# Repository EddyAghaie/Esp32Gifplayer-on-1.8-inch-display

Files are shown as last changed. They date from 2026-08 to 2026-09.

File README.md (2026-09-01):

# Esp32Gifplayer-on-1.8-inch-display

⚠️ **Please read the README before using this project.**

A high-speed ESP32 GIF player with Wi-Fi upload, optimized playback, 1.8" ST7735 TFT support, and LittleFS storage.

# ESP32 High-Speed GIF Player

This project is designed as one of the **fastest and simplest ways to play GIF animations on a standard ESP32 over Wi-Fi**, without requiring an SD card or an internet connection.

GIFs are uploaded from a smartphone over Wi-Fi, processed directly in the browser, converted into an optimized custom binary format, and stored in **LittleFS**. The ESP32 then reads the optimized frames directly from flash memory and plays them continuously on the TFT display.

The hardware is designed around a **Wemos D1 Mini ESP32**, a **1.8-inch ST7735 TFT display**, and a compact **650mAh 3.7V Li-ion battery** with a **TP4056 charging module**.

---

# Features

* ⚡ High-speed GIF playback
* 📺 1.8-inch ST7735 TFT display
* 🖥️ 160×128 landscape resolution
* 📡 Built-in ESP32 Wi-Fi Access Point
* 📱 Upload GIFs directly from a smartphone
* 💾 Store animations in LittleFS
* 🚫 No SD card required
* 🌐 No internet connection required
* 🚀 Optimized SPI display communication
* 🧩 Custom lightweight `GFA1` animation format
* 🔄 Continuous GIF playback
* 📷 Automatic QR code generation
* 📱 Mobile-friendly upload interface
* 📲 PWA support / Add to Home Screen
* 🔄 Factory reset using 5 power cycles
* 💻 GIF decoding is performed in the browser using pure JavaScript
* 📦 Maximum 30 output frames per GIF
* 🔋 650mAh 3.7V Li-ion battery
* 🔌 TP4056 Li-ion battery charging
* ⏻ ON/OFF power switch
* 🧳 Portable battery-powered design

---

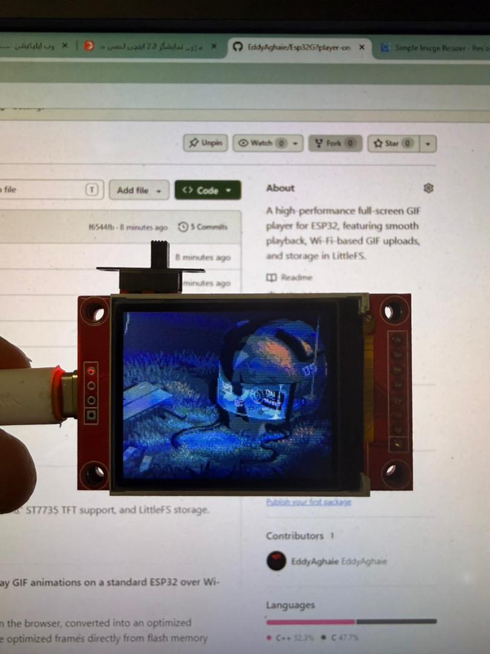
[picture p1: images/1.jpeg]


---

# Hardware

## Required Hardware

* **Wemos D1 Mini ESP32**
* 1.8-inch ST7735 SPI TFT display, 160×128
* **650mAh 3.7V Li-ion battery**
* **TP4056 Li-ion charging module with USB input**
* ON/OFF slide switch
* 5V USB power source for charging
* Jumper wires
* Appropriate regulated power circuit for the ESP32

The project uses a **Wemos D1 Mini ESP32** as the main controller.

The device does not require:

* ESP32-S3
* ESP32-C3
* SD card
* Internet connection
* Cloud service

---

# Power & Charging

The project uses a **650mAh 3.7V Li-ion battery** as the portable power source.

The TP4056 module is used for **charging the Li-ion battery**.

## Battery Connection

Connect the battery to the battery terminals of the TP4056:

```text
650mAh Li-ion Battery
       │
       ├── Battery + ───────> TP4056 BAT+
       │
       └── Battery − ───────> TP4056 BAT−
```

## USB Charging

The TP4056 module is charged through its **USB input**.

Simply connect a standard **5V USB power source** to the USB port on the TP4056:

```text
5V USB Charger
      │
      ▼
TP4056 USB Port
      │
      ▼
650mAh Li-ion Battery
```

No separate wiring to `IN+` or `IN−` is required when using the USB connector on the TP4056 module.

> **Important:** Use a suitable 5V USB power source for charging. Do not connect the battery to the USB input.

---

# Power Switch

The ON/OFF switch is placed in the positive power path between the battery power output and the ESP32 power circuit.

Recommended power flow:

```text
650mAh 3.7V Li-ion Battery
          │
          ▼
     ON/OFF Switch
          │
          ▼
 Proper Voltage Regulation
          │
          ▼
 Wemos D1 Mini ESP32
```

The TP4056 remains responsible for charging the battery through its USB connector.

> **Important:** The TP4056 is a battery charger, not a 3.3V regulator. Do not connect a raw 3.7–4.2V Li-ion battery directly to the ESP32 `3V3` pin. Use the appropriate regulated power circuit for the Wemos D1 Mini ESP32.

---

# Complete Power Flow

```text
                USB 5V
                  │
                  ▼
           ┌─────────────┐
           │   TP4056    │
           │ USB Charger │
           └──────┬──────┘
                  │
                  ▼
        650mAh 3.7V Li-ion
                  │
                  ▼
            ON/OFF Switch
                  │
                  ▼
        Proper Voltage Regulator
                  │
                  ▼
        Wemos D1 Mini ESP32
                  │
                  ▼
             ST7735 TFT
```

---

# TFT Pinout

The following pin configuration is used by the firmware:

| ST7735 Pin | ESP32 GPIO | Function |
| --- | ---: | --- |
| VCC | 3.3V | Power |
| GND | GND | Ground |
| SCK / SCL  | GPIO 18 | SPI Clock |
| SDA / MOSI | GPIO 23 | SPI MOSI |
| CS | GPIO 5 | Chip Select |
| DC / A0 | GPIO 21 | Data / Command |
| RST / RES  | GPIO 2 | Display Reset  |
| LED / BL | GPIO 4 | Backlight |

### Wiring
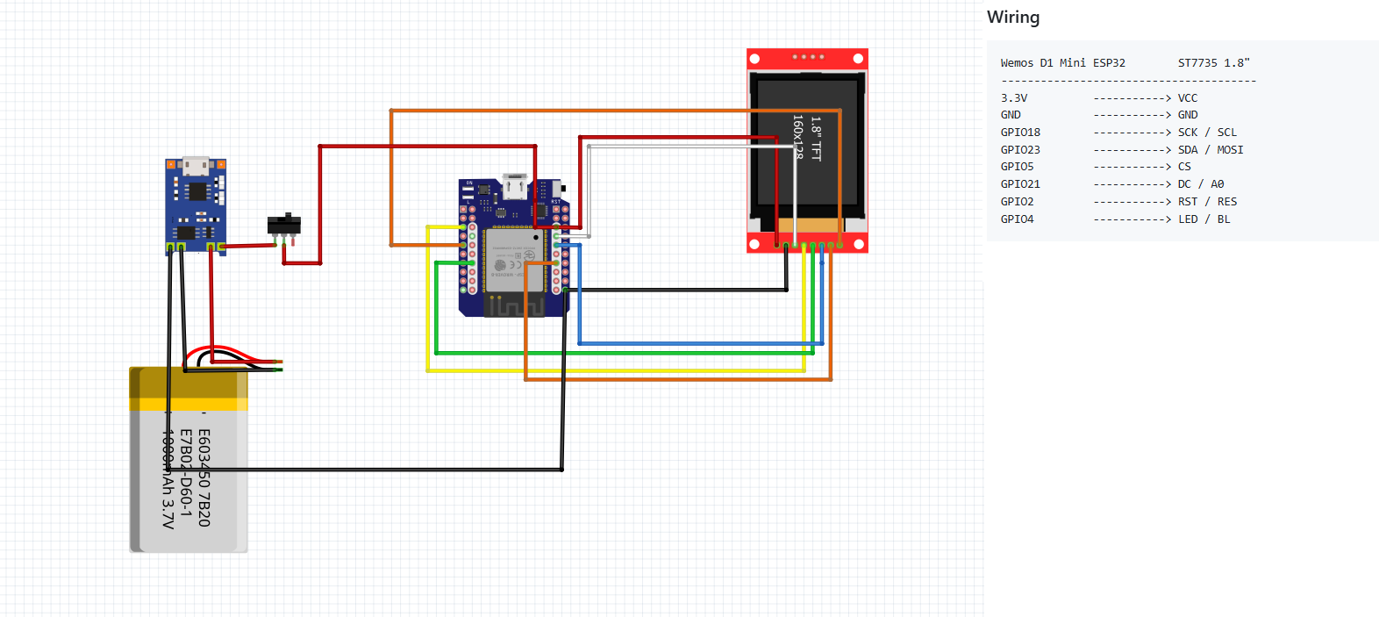
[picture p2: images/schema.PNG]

```text
Wemos D1 Mini ESP32        ST7735 1.8"
---------------------------------------
3.3V          -----------> VCC
GND           -----------> GND
GPIO18        -----------> SCK / SCL
GPIO23        -----------> SDA / MOSI
GPIO5         -----------> CS
GPIO21        -----------> DC / A0
GPIO2         -----------> RST / RES
GPIO4         -----------> LED / BL
```

> **Important:** The display logic is configured for 3.3V. Do not apply 5V directly to 3.3V-only display pins.

---

# ESP32 GPIO Summary

```text
ST7735 SCK  → GPIO18
ST7735 MOSI → GPIO23
ST7735 CS   → GPIO5
ST7735 DC   → GPIO21
ST7735 RST  → GPIO2
ST7735 LED  → GPIO4
```

---

# Display Configuration

The firmware is configured for:

```text
Display:     ST7735
Resolution:  160 × 128
Orientation: Landscape
```

The default rotation is:

```cpp
tft.setRotation(1);
```

If the image is upside down, try:

```cpp
tft.setRotation(3);
```

---

# SPI Configuration

The default ESP32 SPI pins used by the project are:

```text
MOSI = GPIO23
SCK  = GPIO18
```

Display control:

```text
CS  = GPIO5
DC  = GPIO21
RST = GPIO2
BL  = GPIO4
```

---

# Arduino IDE Configuration

Before uploading the firmware, configure Arduino IDE correctly.

## Board

Select:

```text
Tools
→ Board
→ ESP32 Arduino
→ ESP32 Dev Module
```

The firmware uses the standard ESP32 Arduino configuration and is designed to run on the **Wemos D1 Mini ESP32**.

## Recommended Settings

```text
Board:             ESP32 Dev Module
CPU Frequency:     240MHz (WiFi/BT)
Flash Frequency:   80MHz
Flash Mode:        QIO
Upload Speed:      921600
Partition Scheme:  2MB APP / 2MB Filesystem
```

> The exact names of some options may differ depending on your ESP32 Arduino Core version.

---

# Partition Scheme

The recommended partition layout is:

```text
+-----------------------------+
|       APP / Firmware        |
|           2 MB              |
+-----------------------------+
|     LittleFS / Filesystem   |
|           2 MB              |
+-----------------------------+
```

Select a partition scheme that provides approximately:

```text
2 MB APP
2 MB Filesystem
```

Depending on the ESP32 Arduino Core version, the filesystem may be displayed as:

```text
SPIFFS
```

or:

```text
Filesystem
```

Even if the menu says **SPIFFS**, this project uses the **LittleFS API** in the firmware.

The filesystem partition is used to store:

```text
/current.anim
```

and optionally:

```text
/icon.png
```

---

# Required Libraries

Install the following libraries before compiling.

## Adafruit

```text
Adafruit GFX Library
Adafruit ST7735 and ST7789 Library
Adafruit BusIO
```

## ESPAsyncWebServer

Install:

```text
ESPAsyncWebServer
AsyncTCP
```

Use the **ESP32Async** versions compatible with the ESP32 Arduino Core.

## Included with ESP32 Core

These are normally already included:

```text
SPI
WiFi
FS
LittleFS
Preferences
```

## QR Code

The project requires:

```text
QRCodeGen.h
QRCodeGen.c
```

Place both files next to the `.ino` file.

The QR implementation is based on the `ricmoo/QRCode` project with modifications required by this project.

---

# Project Structure

Your project folder should look like:

```text
Esp32Gifplayer-on-1.8-inch-display/
│
├── GifFrame/
│   ├── GifFrame.ino
│   ├── QRCodeGen.h
│   └── QRCodeGen.c
│
├── images/
│   ├── 1.jpeg
│   ├── 2.jpg
│   └── ...
│
└── README.md
```

---

# How the Project Works

The complete process is:

```text
ESP32
  │
  ├── Creates Wi-Fi Access Point
  │
  ▼
QR Code 1
  │
  ▼
Phone connects to ESP32 Wi-Fi
  │
  ▼
QR Code 2
  │
  ▼
http://192.168.4.1/
  │
  ▼
Upload GIF / Image
  │
  ▼
Browser processes the file
  │
  ├── Decode GIF
  ├── Resize
  ├── Crop / Cover
  ├── Convert RGB888 → RGB565
  └── Build GFA1
  │
  ▼
Upload GFA1 to ESP32
  │
  ▼
LittleFS
  │
  ▼
/current.anim
  │
  ▼
ESP32 reads frames
  │
  ▼
ST7735
  │
  ▼
Continuous playback
```

---

# First Boot

When the ESP32 does not have an animation stored in LittleFS, it starts an open Wi-Fi Access Point.

The SSID is automatically generated from the ESP32 MAC address.

Example:

```text
TABLOA1B2
```

The display shows a QR code containing the Wi-Fi configuration.

Scan this QR code with your smartphone to connect to the ESP32.

The Wi-Fi network is open and does not require a password.

---

# Opening the Upload Page

After a smartphone connects to the ESP32 Access Point, the display automatically changes to a second QR code.

This QR code contains:

```text
http://192.168.4.1/
```

Scan it to open the upload page.

You can also manually enter:

```text
http://192.168.4.1
```

into the browser.

No internet connection is required.

---

# Uploading GIFs

The web interface allows you to select an image or GIF from your phone.

Supported image types depend on the browser, including common formats such as:

```text
JPG
PNG
WEBP
BMP
GIF
```

The original GIF is **not** stored on the ESP32.

Instead, the browser processes the GIF before uploading it.

---

# Browser-Side GIF Processing

The ESP32 does not need the `AnimatedGIF` library.

GIF decoding is performed using pure JavaScript running inside the smartphone browser.

The browser performs:

```text
GIF decoding
     ↓
Frame extraction
     ↓
Frame composition
     ↓
Resize / Cover
     ↓
160×128 output
     ↓
RGB888 → RGB565
     ↓
GFA1 generation
     ↓
Wi-Fi upload
```

This significantly reduces the processing required by the ESP32 during playback.

---

# Image Resolution

The target resolution is:

```text
160 × 128
```

Images are automatically resized using a cover-style algorithm.

The goal is to fill the display while avoiding unwanted empty areas.

For animated GIFs, the browser limits the output to:

```text
MAX_FRAMES = 30
```

If the original GIF contains more than 30 frames, frames are sampled to reduce the final file size.

---

# LittleFS Storage

The processed animation is stored as:

```text
/current.anim
```

The ESP32 reads the animation directly from LittleFS.

The animation remains stored after power is removed.

When the ESP32 boots again, it automatically detects:

```text
/current.anim
```

and starts playing it.

---

# GFA1 Format

The project uses a custom binary format called:

```text
GFA1
```

Instead of decoding GIF files on the ESP32, the GIF is converted into raw RGB565 frames.

## File Header

```text
Byte 0-3    : "GFA1"
Byte 4-5    : Width
Byte 6-7    : Height
Byte 8-9    : Frame Count
```

Each frame contains:

```text
2 bytes              Frame delay
width × height × 2   RGB565 pixel data
```

All header integers use little-endian format.

Pixel data is stored in the byte order required by the ST7735 transfer.

---

# Frame Size

Each 160×128 RGB565 frame requires:

```text
160 × 128 × 2
```

which equals:

```text
40,960 bytes
```

approximately:

```text
40 KB per frame
```

Therefore, a 30-frame animation can require roughly:

```text
1.2 MB
```

plus headers and frame delays.

This is why the recommended filesystem partition is:

```text
2 MB
```

---

# Playback

After a successful upload, the ESP32 opens:

```text
/current.anim
```

and starts playing it.

The animation loops continuously:

```text
Frame 1
   ↓
Frame 2
   ↓
Frame 3
   ↓
...
   ↓
Last Frame
   ↓
Frame 1
   ↓
Repeat
```

The display is updated using SPI and the frames are read directly from LittleFS.

---

# Factory Reset

A factory reset is available without a physical reset button.

Power-cycle the ESP32:

```text
ON → OFF
ON → OFF
ON → OFF
ON → OFF
ON → OFF
```

**5 boots within 10 seconds** triggers the factory reset.

The firmware then:

1. Formats LittleFS
2. Deletes the stored animation
3. Resets the boot counter
4. Displays `Factory Reset...`
5. Restarts the ESP32
6. Returns to the initial Wi-Fi QR screen

After this, the device behaves like a new device.

---

# Web Interface

The complete web interface is embedded directly inside the ESP32 firmware.

It does not require:

* Internet
* External web hosting
* CDN
* External JavaScript libraries
* Cloud services

The HTML, CSS and JavaScript are stored in the firmware.

The interface also includes PWA support, allowing the user to add the upload page to the smartphone Home Screen.

---

# PWA

The project includes:

```text
/manifest.json
```

and supports:

```text
Add to Home Screen
```

The upload page can therefore behave more like a small local application.

The project also supports an optional:

```text
/icon.png
```

stored in LittleFS.

---

# ST7735 Offset Configuration

Some 1.8-inch ST7735 displays use different internal GRAM offsets.

The firmware includes:

```cpp
#define COL_START 0
#define ROW_START 0

#define X_OFFSET 0
#define Y_OFFSET 0
```

The default values should normally remain:

```text
COL_START = 0
ROW_START = 0
X_OFFSET  = 0
Y_OFFSET  = 0
```

If your particular display has an incorrectly positioned image, these values can be adjusted.

Do not change them unless necessary.

---

# ST7735 Initialization

The current configuration uses:

```cpp
tft.initR(INITR_BLACKTAB);
```

Some ST7735 modules may require:

```cpp
INITR_GREENTAB
```

or:

```cpp
INITR_144GREENTAB
```

If the display is not initialized correctly, try the appropriate initialization mode for your specific ST7735 module.

---

# Serial Monitor

Open the Arduino Serial Monitor at:

```text
115200 baud
```

During startup, you should see information similar to:

```text
LittleFS: XXXX / XXXX bytes used
AP started: TABLOXXXX
IP: 192.168.4.1
```

After uploading an animation, you should see information about the LittleFS usage.

---

# Important Notes

### 1. Read the README first

This project has specific wiring, partition and library requirements.

**Read the entire README before uploading or modifying the firmware.**

### 2. Use the correct partition

Recommended:

```text
2 MB APP
2 MB LittleFS / Filesystem
```

### 3. Use 3.3V for the display

The project is designed around a 3.3V ESP32 and 3.3V display logic.

### 4. Battery charging

The **650mAh 3.7V Li-ion battery** connects to:

```text
TP4056 BAT+ → Battery +
TP4056 BAT− → Battery −
```

Charging is performed through the TP4056's **USB connector** using a suitable 5V USB power source.

### 5. TP4056 is not a voltage regulator

The TP4056 is responsible for charging the Li-ion battery.

It does **not** regulate the battery voltage to 3.3V.

Use the appropriate regulated power circuit for the Wemos D1 Mini ESP32.

### 6. Do not connect the raw battery to 3V3

The Li-ion battery voltage varies approximately between:

```text
4.2V → fully charged
3.7V → nominal
lower voltage → discharged
```

Therefore, do not connect the battery directly to the ESP32 `3V3` pin.

### 7. GIF size matters

Large GIFs can produce large `GFA1` files.

If the filesystem becomes full, upload a smaller GIF or one with fewer frames.

### 8. Wi-Fi is open

The ESP32 Access Point intentionally uses no password.

Do not use this configuration for sensitive networks.

### 9. Keep SPI wires short

For reliable high-speed SPI communication, keep the TFT wires as short as practical.

Long wires can introduce signal integrity problems, especially at higher SPI clock speeds.

---

# Limitations

```text
Display resolution:     160 × 128
Maximum output frames:  30
Storage:                LittleFS
Display interface:      SPI
Wi-Fi:                  ESP32 Access Point
Battery:                650mAh 3.7V Li-ion
Charging:               TP4056 USB
External SD card:       Not required
Internet:               Not required
```

The actual maximum animation size depends on the filesystem partition and available LittleFS space.

---

# Technologies

This project uses:

* Wemos D1 Mini ESP32
* Arduino Framework
* C++
* SPI
* ST7735
* Adafruit GFX
* ESPAsyncWebServer
* AsyncTCP
* Wi-Fi AP
* LittleFS
* Preferences / NVS
* HTML
* CSS
* JavaScript
* QR Code generation
* Custom GFA1 binary format
* RGB565
* TP4056 Li-ion charging
* 650mAh Li-ion battery

---

# Why GFA1?

The main reason for creating the `GFA1` format is performance.

Instead of asking the ESP32 to:

```text
Read GIF
   ↓
Decode GIF
   ↓
Process frames
   ↓
Resize
   ↓
Convert colors
   ↓
Display
```

the phone performs the expensive processing first:

```text
Phone
  ↓
Decode
  ↓
Resize
  ↓
Convert
  ↓
GFA1
  ↓
ESP32
  ↓
Read frame
  ↓
Display
```

The ESP32 therefore has a much simpler job during playback: read RGB565 frame data from LittleFS and send it to the ST7735 over SPI.

This approach is specifically designed to achieve very fast and lightweight GIF playback on a standard ESP32.

---

# Quick Start

```text
1. Read this README completely
          ↓
2. Install Arduino IDE
          ↓
3. Install ESP32 Arduino Core
          ↓
4. Select ESP32 Dev Module
          ↓
5. Select 2MB APP + 2MB Filesystem
          ↓
6. Install required libraries
          ↓
7. Add QRCodeGen.h and QRCodeGen.c
          ↓
8. Connect the ST7735 using the pinout above
          ↓
9. Connect the 650mAh Li-ion battery to TP4056 BAT+ / BAT−
          ↓
10. Connect a 5V USB charger to the TP4056 USB port
          ↓
11. Connect the ON/OFF switch to the power path
          ↓
12. Connect the regulated power output to the Wemos D1 Mini
          ↓
13. Upload the firmware
          ↓
14. Open Serial Monitor at 115200
          ↓
15. Connect your phone to the TABLOXXXX Wi-Fi
          ↓
16. Scan the second QR code
          ↓
17. Select an image or GIF
          ↓
18. Wait for browser processing
          ↓
19. Upload the generated GFA1 file
          ↓
20. ESP32 stores it in LittleFS
          ↓
21. GIF starts playing automatically
```

---

# Project Goal

The goal of **GifFrame** is to provide a fast, simple and standalone way to turn an ESP32 and a small ST7735 TFT display into a Wi-Fi controlled GIF frame.

The project moves GIF processing to the smartphone and keeps the ESP32 playback system lightweight and optimized for speed.

With the compact battery-powered hardware, the device can operate as a **portable standalone GIF display** without requiring an SD card, internet connection, or external server.

```text
Wemos D1 Mini ESP32
        +
    ST7735 TFT
        +
   Wi-Fi Upload
        +
    LittleFS
        +
650mAh Li-ion Battery
        +
      TP4056
        =
Portable High-Speed GIF Frame
```

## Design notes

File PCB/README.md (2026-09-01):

# PCB Design

The PCB design for this project is provided in the `PCB` directory.

The PCB should be treated as the hardware implementation of the wiring and pin configuration documented in this repository.

## PCB Documentation

All PCB-related work should be based on:

* The wiring diagram provided with this project
* The hardware documentation in this README
* The files inside the `PCB` directory
* The actual firmware GPIO configuration
* The exact hardware components listed in this repository

Do not change GPIO assignments or invent additional connections without verifying them against the project documentation.

## Main PCB Components

The PCB is designed around the following hardware:

* **Wemos D1 Mini ESP32**
* **1.8-inch ST7735 SPI TFT LCD**
* **650mAh 3.7V Li-ion battery**
* **TP4056 Li-ion charging module with built-in USB connector**
* **ON/OFF slide switch**

## TFT Connections

The TFT uses the following connections:

| TFT Pin | Wemos D1 Mini ESP32 |
| --- | --- |
| VCC | 3.3V |
| GND | GND |
| SCK / SCL  | GPIO18 |
| MOSI / SDA | GPIO23 |
| CS | GPIO5 |
| DC / A0 | GPIO21 |
| RST / RES  | GPIO2 |
| LED / BL | GPIO4 |

These GPIO assignments must remain unchanged unless the firmware is also modified accordingly.

## Power & Charging

The TP4056 is used as the Li-ion battery charging module.

The battery is connected to the TP4056 battery terminals:

```text
650mAh 3.7V Li-ion Battery
        │
        ├── + → TP4056 B+
        │
        └── − → TP4056 B−
```

Charging is performed through the **USB connector already integrated into the TP4056 module**.

```text
USB-C 5V Charger
        │
        ▼
   TP4056 USB Port
        │
        ▼
  Li-ion Battery
```

There is no separate USB charging module.

There is no separate USB connector added to the PCB.

## ON/OFF Switch

The ON/OFF switch is placed in the positive power path of the device.

The switch controls the power supplied to the ESP32 system.

```text
Battery
   │
   ▼
ON/OFF Switch
   │
   ▼
ESP32 Power
```

## Important PCB Design Rules

When modifying or manufacturing the PCB:

1. Use the exact components documented in this repository.
2. Follow the wiring diagram exactly.
3. Do not change the TFT GPIO assignments.
4. Do not add components that are not part of the documented circuit.
5. Do not add a separate USB charging connector; the TP4056 already contains the USB charging port.
6. Do not connect the battery directly to the TFT signal pins.
7. Do not connect 5V directly to 3.3V-only TFT logic pins.
8. Verify every PCB trace against the corresponding wiring connection before manufacturing.
9. Check polarity of the Li-ion battery and TP4056 connections carefully.
10. Confirm that the ON/OFF switch is installed in the correct power path.

## PCB Files

The latest PCB-related files and design assets are located in:

```text
PCB/
```

Use the files in this directory together with the wiring documentation when reviewing, modifying, or manufacturing the board.

The repository is the primary source of truth for this project. When there is a conflict between an external drawing and the actual project files or firmware, verify the connection against the firmware and project documentation before proceeding.

## Repository

Project repository:

[Esp32Gifplayer-on-1.8-inch-display](https://github.com/EddyAghaie/Esp32Gifplayer-on-1.8-inch-display/tree/main?utm_source=chatgpt.com)

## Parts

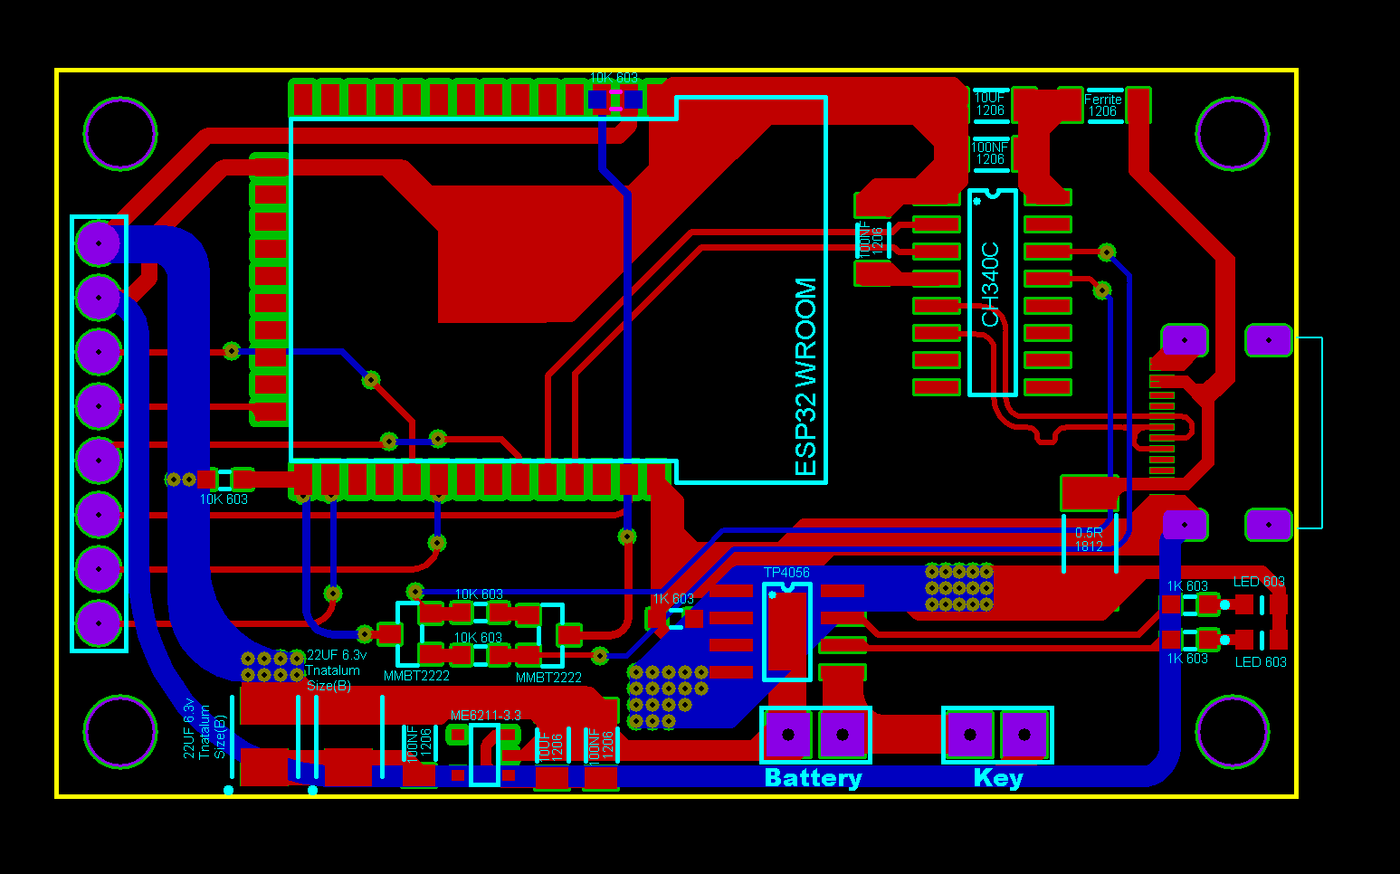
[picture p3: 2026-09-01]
PCB/ESP BOM.BMP

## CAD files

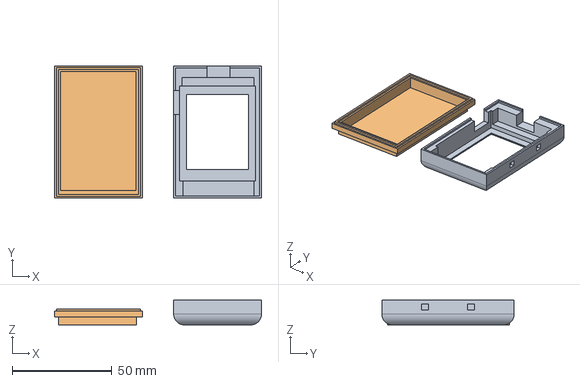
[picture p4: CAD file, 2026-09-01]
3D Print File/ST7735 Bezel.step
103.6 x 66.3 x 12.5 mm

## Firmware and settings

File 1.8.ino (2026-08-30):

/*
  ====================================================================
  GifFrame - ESP32 + ST7735 1.8" (160x128 Landscape) WiFi Image/GIF Frame
  ====================================================================
  پین‌بندی نهایی:
    SDA (MOSI) = GPIO23
    SCK        = GPIO18
    CS         = GPIO5
    LED (BL)   = GPIO4
    RESET      = GPIO2
    DC         = GPIO21
    VCC -> 3.3V , GND -> GND

  کتابخانه‌های لازم (از Library Manager نصب کنید):
    - Adafruit GFX Library
    - Adafruit ST7735 and ST7789 Library (+ Adafruit BusIO)
    - ESPAsyncWebServer + AsyncTCP  (فورک ESP32Async از گیت‌هاب - ZIP)
    - LittleFS (داخل هسته ESP32)
    - Preferences (داخل هسته ESP32)
    - QRCodeGen.h / QRCodeGen.c (کنار فایل .ino - فایل‌های ricmoo/QRCode با اصلاح bool)

  نکته: AnimatedGIF دیگر لازم نیست. پردازش/ریسایز کاملاً سمت گوشی
        با جاوااسکریپت خالص (بدون نیاز به اینترنت/CDN) انجام می‌شود
        و یک فرمت باینری سبک سفارشی به نام "GFA1" به دستگاه ارسال می‌شود.

  منطق کلی:
    1) بوت اول (هیچ فایلی ذخیره نشده): صفحه QR1 با پس‌زمینه سفید نشان داده
       می‌شود - برای اتصال خودکار گوشی به وای‌فای دستگاه (بدون پسورد).
    2) به محض اتصال یک کلاینت به AP (رویداد WiFi)، صفحه به QR2 با پس‌زمینه
       قرمز تغییر می‌کند که آدرس "http://192.168.4.1/" را کد کرده -
       با اسکن، صفحه تنظیمات مستقیماً در مرورگر گوشی باز می‌شود (بدون
       نیاز به Captive Portal، که در iOS محدودیت‌های زیادی دارد).
    3) صفحه‌ی وب: آپلود هر عکس/گیف از گالری گوشی + راهنمای انگلیسی برای
       افزودن به Home Screen یا ذخیره آدرس 192.168.4.1.
       مرورگر خودش عکس/گیف رو دیکود، cover (پر کردن کامل صفحه بدون فضای
       خالی) به 160x128 ریسایز، و به فرمت "GFA1" (هدر + فریم‌های RGB565
       خام) تبدیل و آپلود می‌کند.
    4) ESP32 فایل "/current.anim" را ذخیره و به‌صورت لوپ دائم پخش می‌کند؛
       از این لحظه صفحات QR دیگر نمایش داده نمی‌شوند.
    5) فکتوری ریست: شمارش 5 بار روشن/خاموش در بازه 10 ثانیه با Preferences (NVS)
       -> پاک کردن LittleFS و ریست تنظیمات (برگشت به صفحه QR1).

  فرمت فایل "/current.anim" (GFA1):
    بایت 0-3   : "GFA1"
    بایت 4-5   : width  (uint16, little-endian) -> باید برابر SCREEN_W باشد
    بایت 6-7   : height (uint16, little-endian) -> باید برابر SCREEN_H باشد
    بایت 8-9   : frameCount (uint16, little-endian)
    سپس به ازای هر فریم:
      2 بایت delay_ms (uint16, little-endian)
      width*height*2 بایت پیکسل RGB565 (هر پیکسل 2 بایت big-endian/wire order)

  ====================================================================
*/

#include <SPI.h>
#include <Adafruit_GFX.h>
#include <Adafruit_ST7735.h>
#include <FS.h>
#include <LittleFS.h>
#include <WiFi.h>
#include <ESPAsyncWebServer.h>
#include <Preferences.h>
#include "QRCodeGen.h" // کتابخانه QRCode (ricmoo) - فایل‌های QRCodeGen.h/.c باید کنار .ino باشن

// ---------------- پین‌بندی ----------------
#define TFT_CS   5
#define TFT_DC   21
#define TFT_RST  2
#define TFT_LED  4
// MOSI=23 (SDA), SCK=18 -> پیش‌فرض HSPI/VSPI روی ESP32 همین‌ها هستند

#define SCREEN_W 160
#define SCREEN_H 128

// اگر تصویر روی نمایشگر شیفت/کراپ/wrap شده دیده شد، این مقادیر را تغییر بده.
// 2,1 رایج‌ترین مقدار برای پنل‌های 1.8" ST7735 (132x162 GRAM روی پنل 128x160) است.
// مقادیر دیگری که می‌توان امتحان کرد: (0,0), (2,3), (1,2), (3,2), (4,0)
// با کد اولیه (offset=0,0) تصاویر کامل و بدون موج/کجی نمایش داده می‌شدن.
// تغییر این مقادیر باعث موج‌دار/کج‌شدن تصویر می‌شود - دست نزنید مگر مطمئن باشید.
#define COL_START 0
#define ROW_START 0

// X_OFFSET/Y_OFFSET برای تنظیم ریز (fine-tuning) اضافه، معمولاً 0 بماند.
#define X_OFFSET 0
#define Y_OFFSET 0

// کلاس کوچک مشتق‌شده فقط برای دسترسی به setColRowStart که در کتابخونه protected است
class Adafruit_ST7735_Custom : public Adafruit_ST7735 {
public:
  Adafruit_ST7735_Custom(int8_t cs, int8_t dc, int8_t rst) : Adafruit_ST7735(cs, dc, rst) {}
  void setOffset(int8_t col, int8_t row) { setColRowStart(col, row); }
};

Adafruit_ST7735_Custom tft = Adafruit_ST7735_Custom(TFT_CS, TFT_DC, TFT_RST);
AsyncWebServer server(80);
Preferences prefs;

String apSSID;

// از بخش پخش (پایین‌تر تعریف می‌شود) - برای جلوگیری از دست‌کاری صفحه در حین پخش فریم
extern volatile bool animPlaying;

// ====================================================================
//                     ۱) FACTORY RESET LOGIC
// ====================================================================
// با 5 بار روشن/خاموش در بازه 10 ثانیه از حافظه NVS، ریست فکتوری انجام می‌شود.
void checkFactoryReset() {
  prefs.begin("sysinfo", false);
  uint8_t bootCount = prefs.getUChar("bootcnt", 0);

  bootCount++;
  if (bootCount >= 5) {
    Serial.println("== FACTORY RESET TRIGGERED ==");
    prefs.putUChar("bootcnt", 0);
    prefs.end();

    // پاک کردن کامل LittleFS (شامل فریم فعال و تنظیمات)
    LittleFS.format();

    tft.fillScreen(ST77XX_BLACK);
    tft.setTextColor(ST77XX_WHITE);
    tft.setTextSize(1);
    tft.setCursor(10, 60);
    tft.println("Factory Reset...");
    delay(1500);
    ESP.restart();
    return;
  }

  prefs.putUChar("bootcnt", bootCount);
  prefs.end();
}

void resetBootCounterAfterTimeout() {
  static unsigned long startTime = millis();
  static bool done = false;
  if (!done && millis() - startTime > 10000) {
    prefs.begin("sysinfo", false);
    prefs.putUChar("bootcnt", 0);
    prefs.end();
    done = true;
  }
}

// ====================================================================
//                     ۲) صفحات QR (Landscape) - دو مرحله‌ای
// ====================================================================
// QR_VERSION=4 برای هر دو متن (WiFi config و URL) کافی است.
// سایز بافر = ((4*version+17)^2 + 7) / 8  ->  برای version=4: ((33*33)+7)/8 = 137
#define QR_VERSION 4
#define QR_BUFFER_SIZE 137
uint8_t qrcodeBuffer[QR_BUFFER_SIZE];

// رسم ماژول‌های QR در یک مستطیل مشخص
void drawQRModules(QRCode &qrcode, int offsetX, int offsetY, int pixelSize, uint16_t fg, uint16_t bg) {
  for (uint8_t y = 0; y < qrcode.size; y++) {
    for (uint8_t x = 0; x < qrcode.size; x++) {
      uint16_t color = qrcode_getModule(&qrcode, x, y) ? fg : bg;
      tft.fillRect(offsetX + x * pixelSize, offsetY + y * pixelSize, pixelSize, pixelSize, color);
    }
  }
}

// محاسبه‌ی اندازه و موقعیت QR وسط‌چین (هم افقی هم عمودی) با کمی فضا برای یک برچسب بالای آن
void computeQRLayoutCentered(QRCode &qrcode, int &offsetX, int &offsetY, int &pixelSize, int &totalSize, int topReserved) {
  const int sideMargin = 6;
  const int bottomMargin = 4;
  int availW = SCREEN_W - sideMargin * 2;
  int availH = SCREEN_H - topReserved - bottomMargin;

  pixelSize = min(availW / qrcode.size, availH / qrcode.size);
  if (pixelSize < 1) pixelSize = 1;
  totalSize = pixelSize * qrcode.size;

  offsetX = (SCREEN_W - totalSize) / 2 + X_OFFSET;
  offsetY = topReserved + (SCREEN_H - topReserved - totalSize) / 2 + Y_OFFSET;
}

// رسم یک برچسب کوچک وسط‌چین در بالای صفحه
void drawTopLabel(const char* text, uint16_t fg, uint16_t bg) {
  tft.setTextColor(fg, bg);
  tft.setTextSize(1);
  int textW = strlen(text) * 6; // هر کاراکتر در سایز 1 حدوداً 6px
  int x = (SCREEN_W - textW) / 2;
  if (x < 0) x = 0;
  tft.setCursor(x, 4);
  tft.println(text);
}

// -------- مرحله ۱: صفحه اتصال به وای‌فای (پس‌زمینه سفید) --------
// -------- مرحله ۱: صفحه اتصال به وای‌فای (پس‌زمینه سفید) --------
void drawConnectScreen() {
  tft.fillScreen(ST77XX_WHITE);

  String qrText = "WIFI:T:nopass;S:" + apSSID + ";;";
  QRCode qrcode;
  qrcode_initText(&qrcode, qrcodeBuffer, QR_VERSION, ECC_MEDIUM, qrText.c_str());

  const int topReserved = 16;
  int offsetX, offsetY, pixelSize, totalSize;
  computeQRLayoutCentered(qrcode, offsetX, offsetY, pixelSize, totalSize, topReserved);

  drawTopLabel("WiFi Connect", ST77XX_BLACK, ST77XX_WHITE);
  drawQRModules(qrcode, offsetX, offsetY, pixelSize, ST77XX_BLACK, ST77XX_WHITE);
}

// -------- مرحله ۲: صفحه باز کردن صفحه تنظیمات (پس‌زمینه قرمز) --------
void drawOpenPageScreen() {
  tft.fillScreen(ST77XX_RED);

  String url = "http://192.168.4.1/";
  QRCode qrcode;
  qrcode_initText(&qrcode, qrcodeBuffer, QR_VERSION, ECC_MEDIUM, url.c_str());

  const int topReserved = 16;
  int offsetX, offsetY, pixelSize, totalSize;
  computeQRLayoutCentered(qrcode, offsetX, offsetY, pixelSize, totalSize, topReserved);

  // کادر سفید پشت QR برای کنتراست بهتر روی پس‌زمینه قرمز
  tft.fillRect(offsetX - 4, offsetY - 4, totalSize + 8, totalSize + 8, ST77XX_WHITE);

  drawTopLabel("Upload Page", ST77XX_WHITE, ST77XX_RED);
  drawQRModules(qrcode, offsetX, offsetY, pixelSize, ST77XX_BLACK, ST77XX_WHITE);
}

// ====================================================================
//                     ۳) راه‌اندازی WiFi AP (بدون Captive Portal)
// ====================================================================

// وقتی هیچ فایل anim پخش نمی‌شود (هنوز در مرحله تنظیمات هستیم)، با اتصال/قطع
// کلاینت‌ها بین صفحه QR1 (اتصال) و QR2 (باز کردن صفحه تنظیمات) سوییچ می‌کنیم.
void onWiFiAPEvent(WiFiEvent_t event) {
  if (animPlaying) return; // اگه قاب در حال پخشه، صفحه رو دست نزن

  if (event == ARDUINO_EVENT_WIFI_AP_STACONNECTED) {
    drawOpenPageScreen();
  } else if (event == ARDUINO_EVENT_WIFI_AP_STADISCONNECTED) {
    if (WiFi.softAPgetStationNum() == 0) {
      drawConnectScreen();
    }
  }
}

void setupWiFiAP() {
  uint8_t mac[6];
  WiFi.macAddress(mac);
  char suffix[5];
  sprintf(suffix, "%02X%02X", mac[4], mac[5]);
  apSSID = "TABLO" + String(suffix);

  WiFi.onEvent(onWiFiAPEvent);
  WiFi.mode(WIFI_AP);
  WiFi.softAP(apSSID.c_str()); // بدون پسورد -> open network

  IPAddress apIP = WiFi.softAPIP(); // معمولاً 192.168.4.1

  drawConnectScreen();
  Serial.println("AP started: " + apSSID);
  Serial.println("IP: " + apIP.toString());
}

// ====================================================================
//                     ۴) پخش فایل GFA1 (لوپ دائم)
// ====================================================================
File animFile;
uint16_t animW = 0, animH = 0, animFrameCount = 0;
const uint32_t ANIM_DATA_START = 10;
uint16_t animFrameIndex = 0;
unsigned long animLastFrameTime = 0;
uint16_t animCurrentDelay = 0;
volatile bool newAnimAvailable = false;
volatile bool animPlaying = false;

bool openCurrentAnim() {
  if (animFile) animFile.close();
  if (!LittleFS.exists("/current.anim")) return false;

  animFile = LittleFS.open("/current.anim", "r");
  if (!animFile) return false;

  uint8_t header[10];
  if (animFile.read(header, 10) != 10) { animFile.close(); return false; }
  if (header[0] != 'G' || header[1] != 'F' || header[2] != 'A' || header[3] != '1') {
    Serial.println("Invalid anim file header");
    animFile.close();
    return false;
  }

  animW = header[4] | (header[5] << 8);
  animH = header[6] | (header[7] << 8);
  animFrameCount = header[8] | (header[9] << 8);

  if (animW != SCREEN_W || animH != SCREEN_H || animFrameCount == 0) {
    Serial.println("Anim size mismatch or empty");
    animFile.close();
    return false;
  }

  animFrameIndex = 0;
  animFile.seek(ANIM_DATA_START);
  tft.fillScreen(ST77XX_BLACK);
  animLastFrameTime = 0;
  animCurrentDelay = 0; // فریم اول فوری نمایش داده شود
  return true;
}

void playAnimTick() {
  if (!animPlaying || !animFile) return;
  if (millis() - animLastFrameTime < animCurrentDelay) return;

  uint8_t db[2];
  if (animFile.read(db, 2) != 2) {
    // پایان فایل -> برگرد به فریم اول (لوپ دائم)
    animFile.seek(ANIM_DATA_START);
    animFrameIndex = 0;
    if (animFile.read(db, 2) != 2) return; // فایل خراب
  }
  uint16_t delayMs = db[0] | (db[1] << 8);
  if (delayMs < 20) delayMs = 100;

  static uint16_t lineBuf[SCREEN_W];

  tft.startWrite();
  tft.setAddrWindow(X_OFFSET, Y_OFFSET, animW, animH);
  for (uint16_t row = 0; row < animH; row++) {
    size_t need = (size_t)animW * 2;
    size_t got = animFile.read((uint8_t*)lineBuf, need);
    if (got != need) {
      memset(lineBuf, 0, sizeof(lineBuf));
    }
    tft.writePixels(lineBuf, animW, false, true); // bigEndian=true: بایت‌ها همان‌طور که نوشته شده‌اند ارسال می‌شوند
  }
  tft.endWrite();

  animFrameIndex++;
  if (animFrameIndex >= animFrameCount) {
    animFrameIndex = 0;
    animFile.seek(ANIM_DATA_START);
  }

  animLastFrameTime = millis();
  animCurrentDelay = delayMs;
}

// ====================================================================
//                     ۵) صفحه وب (HTML/CSS/JS کاملاً آفلاین)
// ====================================================================
const char index_html[] PROGMEM = R"rawliteral(
<!DOCTYPE html>
<html lang="fa" dir="rtl">
<head>
<meta charset="UTF-8">
<meta name="viewport" content="width=device-width, initial-scale=1.0, viewport-fit=cover">
<title>GifFrame</title>
<link rel="manifest" href="/manifest.json">
<link rel="apple-touch-icon" href="/icon.png">
<meta name="apple-mobile-web-app-capable" content="yes">
<meta name="apple-mobile-web-app-status-bar-style" content="black-translucent">
<meta name="theme-color" content="#111111">
<style>
  * { box-sizing: border-box; -webkit-tap-highlight-color: transparent; }
  body {
    margin:0; font-family: -apple-system, 'Segoe UI', Tahoma, sans-serif;
    background: linear-gradient(180deg,#1a1a2e,#0f0f1a); color:#fff; min-height:100vh;
  }
  header {
    padding: 18px 16px; text-align:center; font-size:20px; font-weight:700;
    background: rgba(255,255,255,0.05); backdrop-filter: blur(10px);
    position: sticky; top:0; z-index:10;
  }
  .container { padding: 16px; max-width: 600px; margin: 0 auto; }
  .upload-box {
    border: 2px dashed #555; border-radius: 16px; padding: 30px 16px;
    text-align: center; margin-bottom: 20px; transition: 0.2s;
    background: rgba(255,255,255,0.03);
  }
  .upload-box.dragover { border-color:#6c5ce7; background: rgba(108,92,231,0.1); }
  .upload-box input { display:none; }
  .upload-box label {
    display:inline-block; padding: 12px 24px; border-radius: 12px;
    background: linear-gradient(135deg,#6c5ce7,#a29bfe); color:#fff;
    font-weight:600; cursor:pointer; margin-top:10px;
  }
  .progress-wrap {
    width:100%; height:10px; background:rgba(255,255,255,0.08);
    border-radius:6px; overflow:hidden; margin-top:14px; display:none;
  }
  .progress-bar {
    height:100%; width:0%; background:linear-gradient(135deg,#6c5ce7,#a29bfe);
    transition: width 0.15s;
  }
  .status {
    text-align:center; padding:10px; border-radius:10px; margin-bottom:14px;
    background: rgba(0,255,150,0.1); color:#7fffd4; font-size:14px; display:none;
  }
  .status.show { display:block; }
  .info-banner {
    background: rgba(108,92,231,0.12); border: 1px solid rgba(108,92,231,0.35);
    border-radius: 12px; padding: 12px 14px; margin-bottom: 14px;
    font-size: 13px; line-height: 1.7; text-align: left; direction: ltr;
    position: relative;
  }
  .info-banner b { color: #c2b8ff; }
  .info-banner .close-btn {
    position: absolute; top: 6px; right: 8px; background: none; border: none;
    color: #aaa; font-size: 16px; cursor: pointer; line-height: 1;
  }
  .preview { margin-top:14px; text-align:center; }
  .preview canvas {
    max-width:100%; border-radius:10px; image-rendering: pixelated;
    background:#000; border:1px solid rgba(255,255,255,0.1);
  }
</style>
</head>
<body>
<header>📺 GifFrame</header>
<div class="container">

  <div class="info-banner" id="infoBanner">
    <button class="close-btn" onclick="document.getElementById('infoBanner').style.display='none'">✕</button>
    📌 <b>Tip:</b> Add this page to your Home Screen, or save this address for next time:<br>
    <b>http://192.168.4.1</b>
  </div>

  <div class="status" id="status"></div>

  <div class="upload-box" id="dropZone">
    <div>یک عکس یا GIF بکش اینجا یا انتخاب کن</div>
    <label for="fileInput">انتخاب از گالری</label>
    <input type="file" id="fileInput" accept="image/*">
    <div class="progress-wrap" id="progressWrap">
      <div class="progress-bar" id="progressBar"></div>
    </div>
    <div class="preview" id="preview"></div>
  </div>

</div>

<script>
// ابعاد نمایشگر (Landscape)
const SCREEN_W = 160;
const SCREEN_H = 128;

// بِزِل فیزیکی پنل کمی از ارتفاع بالا/پایین رو می‌پوشونه. برای جلوگیری از
// کراپ‌شدن محتوای مهم تصویر، کاور رو بر اساس یک "ارتفاع ایمن" کوچک‌تر
// محاسبه می‌کنیم (با حاشیه‌ی سیاه ناچیز که زیر بزل پنهان می‌شه).
// اگه هنوز کمی بالا/پایین کراپ بود، این عدد رو کمتر کن (مثلاً 112).
// اگه حاشیه سیاه قابل‌توجه دیدی، بیشترش کن (مثلاً 124).
const VISIBLE_H = 118;

const MAX_FRAMES = 30; // حداکثر فریم خروجی برای جلوگیری از حجم زیاد

function showStatus(msg, ok=true) {
  const s = document.getElementById('status');
  s.textContent = msg;
  s.style.background = ok ? 'rgba(0,255,150,0.1)' : 'rgba(255,80,80,0.15)';
  s.style.color = ok ? '#7fffd4' : '#ff7f7f';
  s.classList.add('show');
}

function setProgress(pct) {
  const wrap = document.getElementById('progressWrap');
  const bar = document.getElementById('progressBar');
  if (pct === null) { wrap.style.display = 'none'; return; }
  wrap.style.display = 'block';
  bar.style.width = pct + '%';
}

// محاسبه سایز "cover": عرض کامل صفحه + ارتفاع "ایمن" (VISIBLE_H) رو پر می‌کند
function fitSize(srcW, srcH) {
  const scale = Math.max(SCREEN_W / srcW, VISIBLE_H / srcH);
  const w = Math.round(srcW * scale);
  const h = Math.round(srcH * scale);
  const x = Math.round((SCREEN_W - w) / 2); // معمولاً <= 0
  const y = Math.round((SCREEN_H - h) / 2); // ممکنه حاشیه کوچک ایجاد کند
  return { w, h, x, y };
}

// ============================================================
// ====== رمزگشای GIF خالص جاوااسکریپت (بدون کتابخونه خارجی) ======
// ============================================================
function parseGifFile(buffer) {
  const data = new Uint8Array(buffer);
  let p = 0;
  function readByte(){ return data[p++]; }
  function readU16(){ const v = data[p] | (data[p+1]<<8); p+=2; return v; }

  if (!(data[0]===0x47 && data[1]===0x49 && data[2]===0x46)) {
    throw new Error('فایل GIF معتبر نیست');
  }
  p = 6;
  const screenW = readU16();
  const screenH = readU16();
  const packed = readByte();
  const gctFlag = (packed & 0x80) !== 0;
  const gctSize = 2 << (packed & 0x07);
  readByte(); // background color index
  readByte(); // aspect ratio
  let gct = null;
  if (gctFlag) {
    gct = [];
    for (let i=0;i<gctSize;i++) gct.push([data[p++],data[p++],data[p++]]);
  }

  const frames = [];
  let gceDelay = 100, gceTransparent = -1, gceDisposal = 0;

  while (p < data.length) {
    const block = readByte();
    if (block === 0x21) { // Extension
      const label = readByte();
      if (label === 0xF9) { // Graphic Control Extension
        readByte(); // block size = 4
        const packed2 = readByte();
        gceDisposal = (packed2 >> 2) & 0x07;
        const hasTransparency = (packed2 & 0x01) !== 0;
        gceDelay = readU16() * 10;
        if (gceDelay === 0) gceDelay = 100;
        const transIdx = readByte();
        gceTransparent = hasTransparency ? transIdx : -1;
        readByte(); // terminator
      } else {
        let size;
        while ((size = readByte()) !== 0) p += size;
      }
    } else if (block === 0x2C) { // Image Descriptor
      const left = readU16();
      const top = readU16();
      const width = readU16();
      const height = readU16();
      const packed3 = readByte();
      const lctFlag = (packed3 & 0x80) !== 0;
      const interlace = (packed3 & 0x40) !== 0;
      const lctSize = 2 << (packed3 & 0x07);
      let lct = null;
      if (lctFlag) {
        lct = [];
        for (let i=0;i<lctSize;i++) lct.push([data[p++],data[p++],data[p++]]);
      }
      const minCodeSize = readByte();
      const bytes = [];
      let size;
      while ((size = readByte()) !== 0) {
        for (let i=0;i<size;i++) bytes.push(data[p++]);
      }
      let indices = lzwDecode(bytes, minCodeSize, width*height);
      if (interlace) indices = deinterlace(indices, width, height);

      frames.push({
        left, top, width, height,
        colorTable: lct || gct || [[0,0,0]],
        transparent: gceTransparent,
        disposal: gceDisposal,
        delay: gceDelay,
        indices
      });
      gceDelay = 100; gceTransparent = -1; gceDisposal = 0;
    } else if (block === 0x3B) {
      break; // Trailer
    } else {
      break; // ناشناخته - برای جلوگیری از حلقه بی‌پایان متوقف شو
    }
  }
  return { width: screenW, height: screenH, frames };
}

function lzwDecode(bytes, minCodeSize, pixelCount) {
  const clearCode = 1 << minCodeSize;
  const eoiCode = clearCode + 1;
  let codeSize, dict;

  function resetDict() {
    dict = [];
    for (let i=0;i<clearCode;i++) dict[i] = [i];
    dict[clearCode] = [];
    dict[eoiCode] = [];
    codeSize = minCodeSize + 1;
  }
  resetDict();

  const output = new Uint8Array(pixelCount);
  let outPos = 0;
  let bitPos = 0;
  const totalBits = bytes.length * 8;

  function readCode() {
    let code = 0;
    for (let i=0;i<codeSize;i++) {
      if (bitPos >= totalBits) return eoiCode;
      const byteIndex = bitPos >> 3;
      const bitIndex = bitPos & 7;
      if ((bytes[byteIndex] >> bitIndex) & 1) code |= (1 << i);
      bitPos++;
    }
    return code;
  }

  let prevCode = -1;
  while (outPos < pixelCount) {
    const code = readCode();
    if (code === clearCode) { resetDict(); prevCode = -1; continue; }
    if (code === eoiCode) break;

    let entry;
    if (dict[code] !== undefined) {
      entry = dict[code];
    } else if (code === dict.length && prevCode !== -1) {
      entry = dict[prevCode].concat([dict[prevCode][0]]);
    } else {
      break; // داده خراب
    }

    for (let i=0;i<entry.length && outPos<pixelCount;i++) output[outPos++] = entry[i];

    if (prevCode !== -1 && dict.length < 4096) {
      dict[dict.length] = dict[prevCode].concat([entry[0]]);
      if (dict.length === (1<<codeSize) && codeSize < 12) codeSize++;
    }
    prevCode = code;
  }
  return output;
}
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
void loop() {
  resetBootCounterAfterTimeout();

  if (newAnimAvailable) {
    newAnimAvailable = false;
    if (openCurrentAnim()) {
      animPlaying = true;
    }
  }

  playAnimTick();

  delay(1);
}

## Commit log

2026-09-01 Create PCB
2026-09-01 Rename ESP BOM.BMP to PCBBOM.BMP
